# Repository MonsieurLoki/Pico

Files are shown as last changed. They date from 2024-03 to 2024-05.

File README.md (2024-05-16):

# Projet Pico Smart Fan
EPHEC, Technologies de l'Informatique, Electronique 2

Groupe J:
- Gaspard Derruine
- Maxime Malpica
- Hugo Noppe
- Dorian Kwizera

## Table of Contents

- [Introduction](#introduction)
- [Features](#features)
- [GitHub](#GitHub)

## Introduction

This is a group project from Ephec students in TI2, Electronics2

## Features

Project objectives :
- implement several functionalities on a Raspberry Pi Pico W
- monitor a temperature sensor and display it on a 2 digit 7-segment
    - use 2 SN74LS47N to drive the 7-segment digits
- when temperature is above MAX, activate fan until it's down below MAX-1
    - a simple 5v fan (DC motor) is used
    - a relay is used to ensure enough power can be given to the fan
    - (an extra power source is added to the Pico 5V source from the USB cable (or battery))
- a web server on the Pico allows to
    - consult that state of the system (temperature, etc)
    - manually control the fan (ON, OFF)
    - the MAX value can be updated with the web interface
- optional
    - implement an LCD 1602 display to show additional information
    - buzzer when temperature above MAX
    - vary the fan speed depending on the temperature (with PWM)
    - leds to indicate status
    - potentiometer (ADC) to adjust reference temperature
    - etc

## GitHub

https://github.com/MonsieurLoki/Pico

Le repository contient:
- les schémas et circuits du PCB
- le code
- le rapport d'avancement et le rapport final

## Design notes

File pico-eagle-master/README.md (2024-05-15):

# pico-eagle

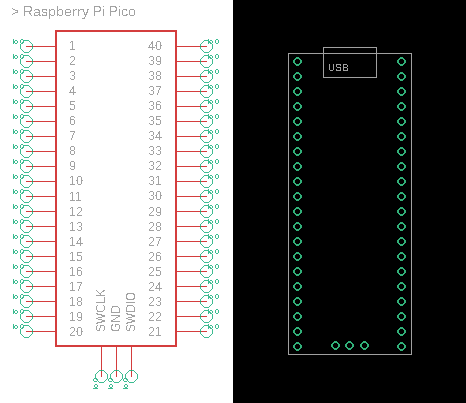
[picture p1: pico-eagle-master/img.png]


**A basic Eagle library for the Raspberry Pi Pico microcontroller board**

* Only a through-hole version is available

Created based on the [Raspberry Pi Pico datasheet](https://datasheets.raspberrypi.org/pico/pico-datasheet.pdf).

~~This has not been tested on an actual PCB - the most testing that has been done is a printed template to check everything looks like it lines up.~~ This has been tested on a PCB from JLCPCB, and it's perfect!

------



<p xmlns:cc="http://creativecommons.org/ns#"  xmlns:dct="http://purl.org/dc/terms/"><a property="dct:title"  rel="cc:attributionURL"  href="https://github.com/codemicro/pico-eagle">pico-eagle</a>  by <a rel="cc:attributionURL dct:creator"  property="cc:attributionName"  href="https://github.com/codemicro">Thomas Pain (codemicro)</a> is marked  with <a  href="http://creativecommons.org/publicdomain/zero/1.0?ref=chooser-v1"  target="_blank" rel="license noopener noreferrer"  style="display:inline-block;">CC0 1.0</p></a>

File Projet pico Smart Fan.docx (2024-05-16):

Mai 2024

Projet Pico Smart Fan

EPHEC, Technologies de l'Informatique, Electronique 2

Groupe J:

Gaspard Derruine

Maxime Malpica

Hugo Noppe

Dorian Kwizera

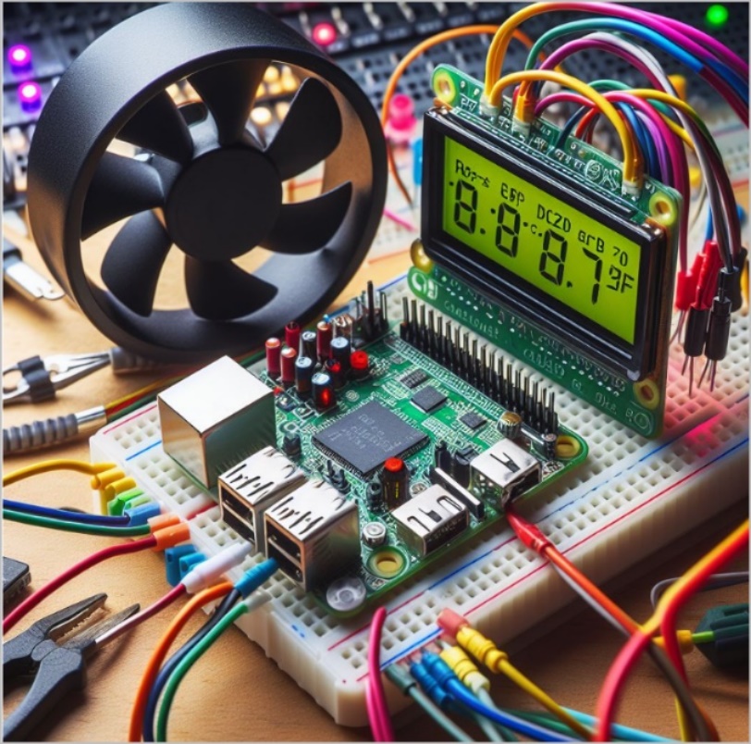
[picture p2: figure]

©DALL-E

# Objectifs du projet

- mettre en oeuvre les connaissances théoriques acquises durant les cours, le cours d'électronique principalement
- acquérir des compétences en matière de gestion de projet
- apprendre à travailler en groupe
- travailler dans le but d'atteindre un résultat concret

# Description du projet

Le groupe a proposé de développer un prototype de ventilateur intelligent, construit autour d'un microcontrôlleur.

Les caractéristiques du projet :

- lire un capteur de température et l'afficher sur un afficheur 7 segments à 2 chiffres.
- utiliser 2 SN74LS47N pour piloter les chiffres du 7 segments
- lorsque la température dépasse une température de référence donnée, activer le ventilateur jusqu'à ce qu'elle revienne à celle-ci
- piloter un ventilateur simple 5V (moteur CC)
- faire varier la vitesse du ventilateur en fonction de la température (avec PWM)
- mettre à jour la valeur de la température de référence avec une interface web
- implémenter un affichage LCD 1602 pour afficher des informations supplémentaires
- alerte sonore lorsque la température dépasse MAX
- LEDs pour indiquer l'état de la température

# Planning

Voici les étapes principales du projet :

- Janvier 2024 : présentation et démarrage du projet
- 21 Février : présentation idée de projet
- 18 Mars : rapport d'avancement
- Mars-Avril-Mai : travail de groupe
- 17 Mai : présentation du produit final

Les tâches détaillées sont reprises en Annexe 1.

# Simulation

Pour démarrer le projet, nous avons effectué quelques simulations de circuits sur Wokwi, mais nous sommes rapidement arrivés aux limites de ce qu'on peut faire d'utile pour un projet comme le nôtre, où la partir code est relativement importante.

# Le PCB

Le PCB a été développé sur l'outil Eagle, qui a demandé pas mal d'apprentissage. Le passage du schema logique au circuit a amené pas mal de surprises lorsque nous avons dû intégrer les contraintes physiques.

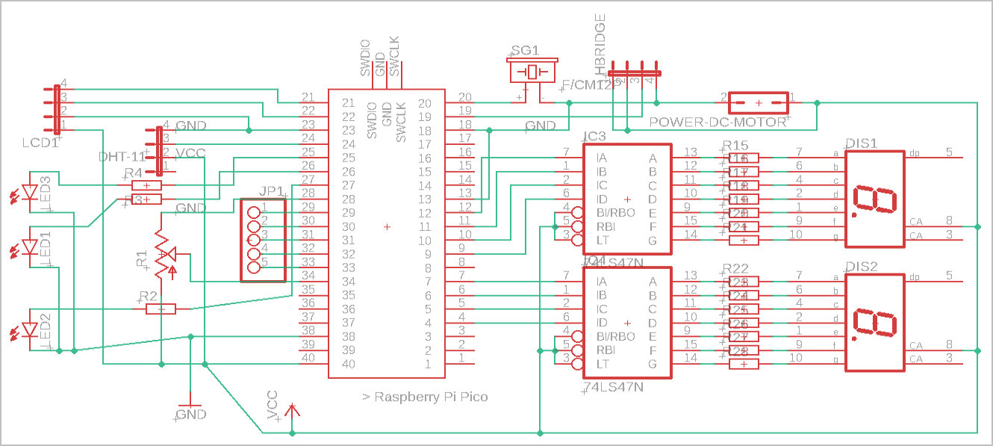
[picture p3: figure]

Ici aussi, les ressources offertes par Internet (tutos, YouTube, OpenAI etc) ont été fortement consultées.

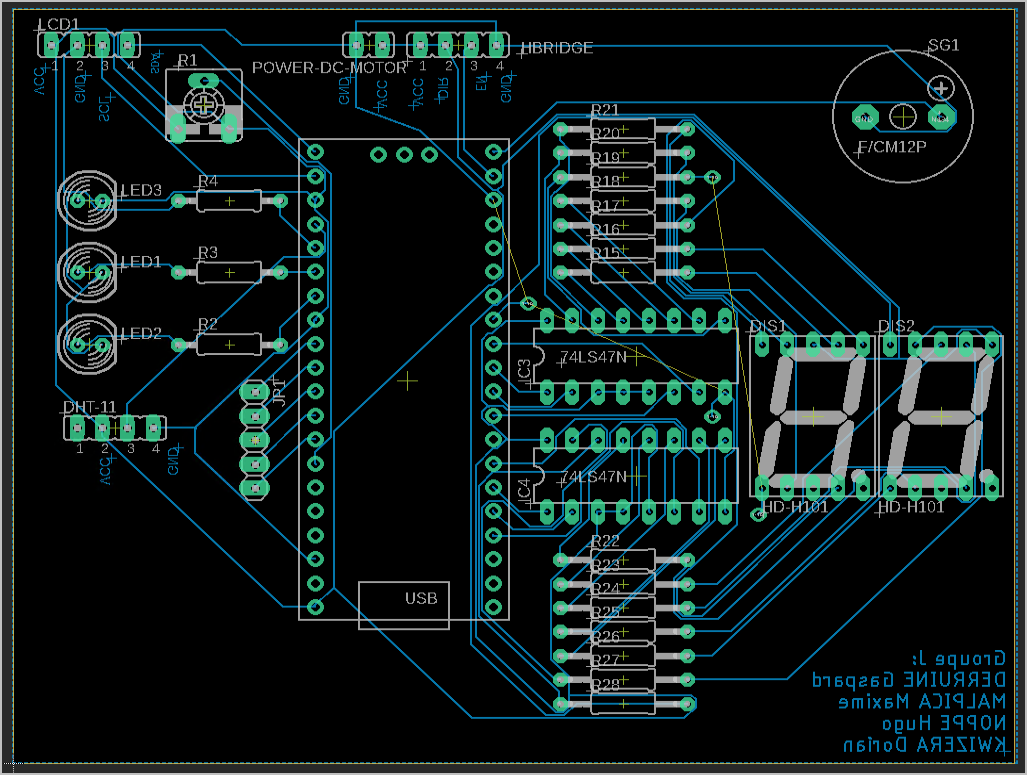
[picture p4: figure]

# Les composants

Les composants utilisés pour ce projet :

- Raspberry Pico W
- 2 74LS47 et 2 7segments + résistances de protection 220 ohms
- dht11
- LCD1602
- buzzer piezzo
- 3 leds
- potentiomètre 2K (ADC)
- ventilateur DC 5V
- PModHB5 (contrôleur moteur DC)

# Le code

Le code micropython a été réalisé de façon modulaire. Chaque composant (LEDs, 7segment + 74LS47, LCD, buzzer, moteur DC + PWM, potentiomètre ADC, etc) a son propre module python, ce qui permet de tester chaque composant individuellement, et de l'intégrer de façon très propre et très efficace dans le module principal du projet.

Le code est structuré de cette façon :

- main.py (main + wifi + webserver)
  - params.py (paramètres wifi)
  - 74LS47_7segments.py (affichage 7segments)
  - lcd.py (LDC1602)
  - dht11.py (capteur de temperature)
  - leds.py (leds)
  - buzzer.py (alarme sonore)

La partie la plus délicate a été la gestion évènementielle et les appels à des procédures asynchrones (que nous ne maîtrisons pas encore tout à fait).

# Github

Notre repository sur github : https://github.com/MonsieurLoki/Pico

Ce repository contient :

- les schémas pour le PCB
- le code micropython
- la documentation

# Le résultat final

Malgré les difficultés techniques et organisationnelles, nous sommes plutôt satisfaits du résultat final.

Notre projet fonctionne réellement et répond aux spécifications initiales. Nous avons appris énormément et avons plein d'idées sur la façon dont ce projet pourrait être continué, et comment un nouveau projet pourrait bénéficier de toute l'expérience acquise durant les semaines précédentes.

Le prototype final: L'interface web :

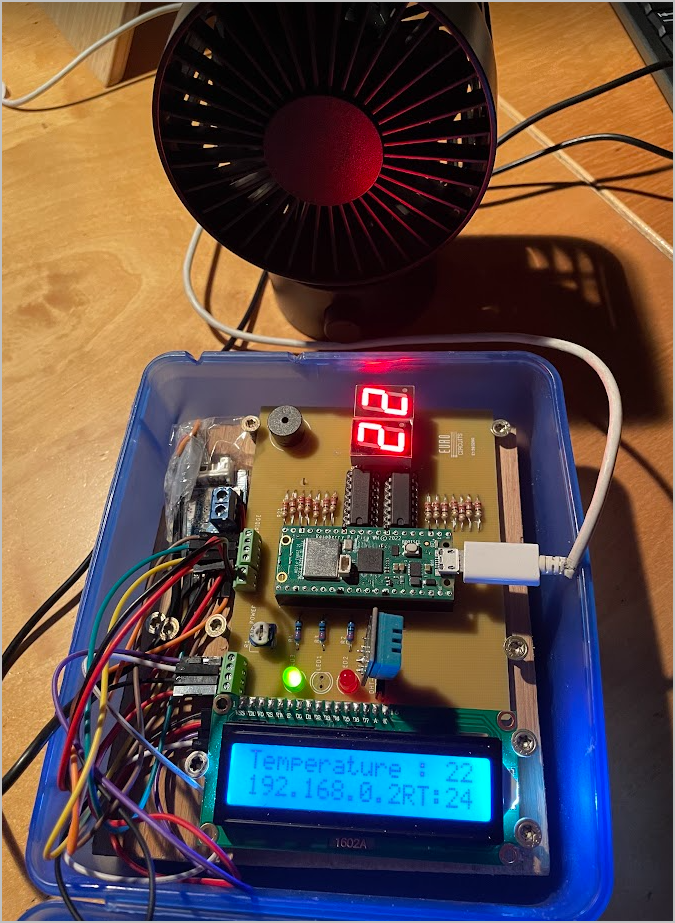
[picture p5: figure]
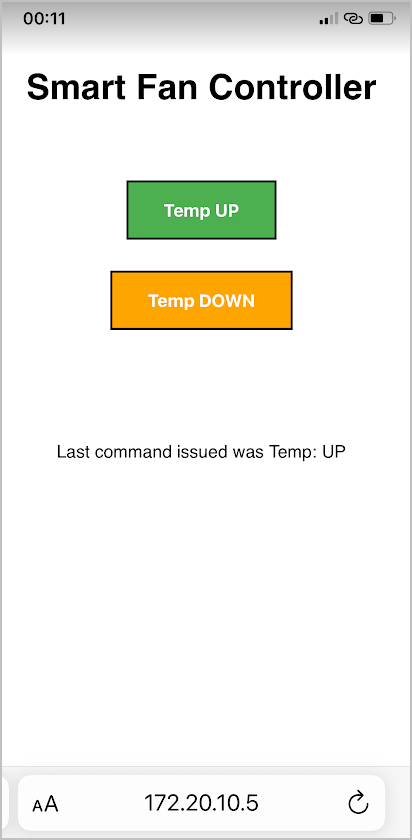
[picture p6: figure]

# Les difficultés rencontrées

## Le PCB

Le design et la réalisation du PCB a été une expérience complètement nouvelle pour tous les membres du groupe. La mise en pratique des techniques vues au cours a demandé pas mal d'efforts et a été une expérience relativement stressante, entre autres à cause du fait qu'il est difficile de simuler le bon fonctionnement du PCB avec les outils à notre disposition, et le fait que dès que le schéma du PCB part vers le fabricant, il est très compliqué de corriger une erreur de design.

## Le matériel

Les composants électroniques n'étant pas en nombre suffisant pour que tout le monde ait un exemplaire de chaque composant (et en particulier du PCB ), il a fallu se répartir les tâches autrement (contributions au design du PCB, à la documentation, au code, à l'implémentation des composants individuellement sur breadboard, etc). L'un de nous s'est consacré à l'intégration des composants sur le PCB et l'intégration du code.

## Micropython

Python est un langage nouveau pour la plupart des membres du groupe et le niveau de chacun est différent. Grâce à notre connaissance des langages appris dans les cours précédents (C, Javascript), et avec l'aide de l'IA, il a cependant été possible de réaliser la plupart des objectifs du projet, et surtout d'apprendre énormément.

## GitHub

Nous avons commencé à utiliser GitHub l'année dernière pour des projets individuels. Travailler en groupe avec GitHub, et surtout pour un projet en micropython sur un microcontroller, et moins évident, d'autant plus si tout le monde n'a pas tout le matériel à disposition.

## Le travail de groupe

Contribuer à un projet de développement de software en groupe, comme le projet Formule 1 du premier quadri, est une chose. Collaborer efficacement sur un projet matériel est plus compliqué, dû aux évidentes contraintes physiques.

# Extension possible du projet

Avec quelques jours de plus, les fonctionnalités suivantes seraient facilement implémentables sur notre prototype :

- consulter l'état du système (température, etc.) via l'appli web
- contrôler manuellement le ventilateur (MARCHE, ARRÊT) via l'appli web
- potentiomètre (ADC) pour ajuster la température de référence (celui-ci est déjà prévu dans le design initial et soudé sur le PCB)

# Conclusions

## Hugo

Personnellement j'ai trouvé ce projet très intéressant car il nous a introduit à la création de PCB, et la familiarisation aux microcomputer, c’est une expérience que je n’avais jamais eu l’occasion de faire. Cela m’ouvre des portes à la réalisation de plus grands projets personnels. Grâce à l’aide des profs nous avons su mener à bien ce projet.

## Dorian

J’ai finalement beaucoup aimé ce projet. La partie du codage me faisait un peu peur mais finalement, en allant d’étape en étape, cela c’est très bien passé et le résultat est encore mieux que l’attente initiale. Un des points négatif est le faite qu’une seul personne du groupe pouvait posséder du matériel à la fois, c’ était très compliqué à gérer. Il suffisait d’une absence pour devoir reporter tout une séance de labo par exemple. Mais l’expérience reste bien plus positif que négatif. Et surtout, Il m’a fait réaliser que le Raspberry Pi Pico pouvait nous permettre de contrôler de nombreuse chose de la vie de tous les jours sur notre téléphone (alarmes, garage, store pour fenêtre, chauffage,..) grâce à une page web définie et un serveur web créé pour la servir.

## Maxime

En conclusion, ce projet en électronique a été très enrichissant. La création d'un PCB, avec l'ajout de microcontrôleurs et de capteurs, nous a permis d'avoir un bon aperçu des projets en électronique. Cependant, j'étais stressé par le fait que nous n'avions jamais utilisé de PCB auparavant. Un problème de branchement ou de soudure peut rapidement poser des difficultés, mais heureusement, cela s'est bien passé. Le projet nous a également laissé un large choix pour notre créativité. Merci aux professeurs pour leur encadrement et leur aide à surmonter certains problèmes que nous avons rencontrés.

## Gaspard

Le défi du projet était relativement impressionnant au départ, vu nos connaissances théoriques et pratiques d'il y a quelques mois. Mais le fait d'avoir été poussé à atteindre des objectifs relativement ambitieux m'ont permis de me dépasser et de réaliser qu'en passant le temps nécessaire, et en cherchant suffisamment, principalement sur Internet, il est possible d'approfondir tout seul ou en groupe les concepts abordés au cours et de concrétiser ceux-ci dans un vrai projet. La satisfaction de voir ce montage électronique s'animer progressivement et finalement faire ce qu'on avait prévu qu'il fasse est très grande et m'encourage vraiment à continuer à explorer ce monde à la frontière entre électronique pure et développement de software. La combinaison des deux compétences ouvre des possibilités dont je n'avais pas la moindre idée jusqu'ici.

## Conclusion du groupe

Chacun s'accorde à dire que ce projet n'a pas été simple, qu'il a fallu investir pas mal de temps et d'effort, mais qu'il nous a permis d'apprendre énormément, dans des domaines qui étaient inconnus pour nous jusque-là. Le fait d'avoir un objectif ambitieux, mais aussi la guidance des profs qui nous ont convaincu que c'était possible d'y arriver, nous a finalement permis de dépasser les différentes difficultés techniques et organisationnelles. Le fait de travailler en groupe, au départ une contrainte, a aussi été l'occasion de s'enrichir mutuellement, certains étant plus forts dans certains domaines, et profitant des connaissances des autres dans d'autres.

En conclusion, ce projet restera un très bon souvenir et une excellente façon d'apprendre beaucoup pour réaliser un projet très concret.

# Références bibliographiques et autres

Ce projet a principalement été réalisé sur base des matières vues au cours, des labos et autres travaux pratiques préparatoires. Il n'y a donc pas vraiment de bibliographie à documenter.

Beaucoup de tutos ont été consultés, soit en version statique (wikis), soit en version vidéo (YouTube).

## Raspberry Pico

- Documentation Raspberry Pico : https://www.raspberrypi.com/documentation/microcontrollers/raspberry-pi-pico.html
- Instllation micropython sur Pico: https://www.youtube.com/watch?v=GiT3MzRzG48&ab_channel=CoreElectronics

## Pico micropython :

- Cette ressource en particulier nous a beaucoup aidé car elle nous a permis de comprendre et de régler un problème délicat, à savoir la gestion d'évènements asynchrones sur un microcontroller en micropython :

https://www.youtube.com/watch?v=AK8UYh7pMGM&t=1s&ab_channel=CoreElectronics

- Buzzer : https://www.youtube.com/watch?v=S4zPLBTC7_w
- Web Server : How To Setup a HTTP Web Server With Raspberry Pi Pico W (using WiFi) (https://www.youtube.com/watch?v=AK8UYh7pMGM&ab_channel=CoreElectronics)
- tuto H Bridge Motor Control Basics Explained (https://www.youtube.com/watch?v=YYMsS50x1UY&ab_channel=TheEngineeringMindset)
- tuto controlling motor with Hbridge (moteur : ig220019X00015r, controlleur :
- ow to sound a buzzer : https://www.freva.com/how-to-connect-a-buzzer-to-a-raspberry-pi-pico/
- Hbride DC motor controller : https://digilent.com/reference/pmod/pmodhb5/start
- tuto controlling a DC motor : https://how2electronics-com.translate.goog/dc-motor-fan-speed-controller-with-raspberry-pi-pico/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
- PWM on the Raspberry Pi Pico with MicroPython (https://www.youtube.com/watch?v=hqudYm-a_aU)
- i2c : https://electrocredible.com/raspberry-pi-pico-i2c-tutorial-examples/
- LCD1602 : https://electrocredible.com/raspberry-pi-pico-lcd-16x2-i2c-pcf8574-micropython/

# Annexe : liste détaillée des tâches

## Tasks

Done

- describe project and features
- test components individually
  - dht-11 (temperature sensor)
  - pmod5hb (HBridge driver for a DC motor)
    - fan working
    - speed can be adjusted
  - buzzer

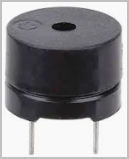
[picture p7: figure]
Alt text

- create github repository
- create first version PCB
- tools -> checks ERC (Electronic Rules Check) and DRC (Design Rules Check)
- add a ground plane

Todo

- make sure all group members have access to the github repo
- check everything (project, features, components, PBC, etc)
- in particular, check PCB
  - schematic : check that each component individually is connected properly (VCC, GND, GPIO)
  - board : check that all connections are done properly (top and bottom layers, no intersections, no hanging wire, etc)
  - optimize signals ( )
  - annotate pinheads on the board
  - check with https://eurocircuits.com
- test components individually
  - 7-segments led + 74LS47
  - LCD1602 display
  - onboard temperature sensor
  - ADC (with variable resistor - potentiometer)
- develop micropython functions to control each component individually, with the GPIOs as planned on the PCB
  - def getValuePot(): (return value between -5 and 5)
  - def initWifi()
  - def initWebServer()
  - def getTemperature()
  - def adjustFan(speed)
  - def displayLCDmsg(msg)
  - def display2digits(value)

## PCB

To be put on the PCB :

- Pico W
- 2x 7-segments DIGIT
  - 7 connections to SN74LS47
  - GND
- SN74LS47N nr 1 (unités)
  - 7 connections to 7-segment
  - GPIO 2 (D), 3 (C), 4 (B), 5 (A) : 4 bits -> 1 digit
  - BI/RBO, RBI, LT connected to VCC
- SN74LS47N nr 2 (dizaines)
  - 7 connections to 7-segment
  - GPIO 6 (D), 7 (C), 8 (B), 9 (A) : 4 bits -> 1 digit
  - BI/RBO, RBI, LT connected to VCC
- fan hbridge
  - GPIO 14 (ENABLE)
  - GND
  - VCC
  - DIRection : VCC (only one direction for the fan)
- buzzer
  - GPIO 15
  - GND
- variable resistor
  - VCC
  - GND
  - ADC 2 (GPIO 28)
- LCD 1602
  - VCC
  - GND
  - SDA (GPIO 16)
  - SCL (GPIO 17)
- DHT-11 sensor
  - GPIO 18 (signal)
  - VCC (5V)
  - GND
- led red
  - GPIO 19
- led red
  - GPIO 20
- led red
  - GPIO 21
- reserve PINs (just in case)
  - 1 : GPIO 22
  - 2 : RUN
  - 3 : GPIO 26
  - 4 : GPIO 27
  - 5 : GPIO 28

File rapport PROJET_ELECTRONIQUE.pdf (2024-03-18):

# Projet - ELECTRONIQUE DIGITALE - T2072

### NOPPE Hugo DERRUINE Gaspard MALPICA ARANA Maxime KWIZERA Dorian

### 18 mars 2024

## Table des matières

1 Introduction | 2
2 Répartition du travail | 2
3 Avancement général | 2
4 Schéma électronique | 3

## 1 Introduction

L’objectif principal de ce projet est de concevoir un proof of concept illustrant les bénéfices d’une maison intelligente. Pour cela, nous disposons d’une variété de capteurs et d’actionneurs, allant des simples boutons poussoirs aux capteurs de température et de mouvement.
Après avoir examiné les différentes possibilités, nous avons décidé de concentrer nos efforts sur la création d’un système autonome de régulation de la température. Notre choix s’est porté sur cette fonctionnalité en raison de sa pertinence dans le contexte de la domotique et de sa faisabilité dans le cadre du projet.
Concrètement, notre système permettra à l’utilisateur de définir une température seuil via une interface web. Le système surveillera ensuite en permanence la température ambiante à l’aide d’un capteur dédié. Si la température dépasse le seuil défini, un ventilateur sera activé pour réguler l’atmosphère. Les informations sur la température seront également affichées sur des afficheurs 7 segments, offrant ainsi une surveillance en temps réel de l’environnement.
Ce rapport présentera en détail notre démarche de conception et d’implémentation, ainsi que les résultats obtenus lors de la réalisation de ce projet.

## 2 Répartition du travail

Nous nous sommes chacun répartis plusieurs tâches. Gaspard à testé le materiel chez lui avec plusieurs petits programmes qu’il a confectionné afin de s’assurer que tout fonctionnait. Ensuite nous nous sommes retrouvés plusieurs fois à l’openlab tous ensembles afin de faire fonctionner tous les composants ensembles. Maxime et Dorian ont travaillés sur les branchements pendant qu’Hugo écrivait le code pour faire fonctionner ces derniers. En parallèle Gaspard à travaillé sur Eagle et nous avons tous vérifié le travail. Finalement Hugo à fini par rédiger ce rapport pour présenter l’avancement du projet. Nous avons également pu profiter de github pour centraliser tout notre travail et se partager les différents fichiers.

## 3 Avancement général

Pour le projet nous avons fini la partie Eagle. Les branchements et la beadboard sont totalement finis. Le code est encore à améliorer. Nous devons juste relier le moteur au système et créer l’interface web pour le programme. Nous avons cependant déjà fait fonctionner le moteur graçe à un code. Celui ci ne doit plus qu’être intégré au reste du code.
Plus de détail se trouve dans le github : https://github.com/MonsieurLoki/Pico

## 4 Schéma électronique

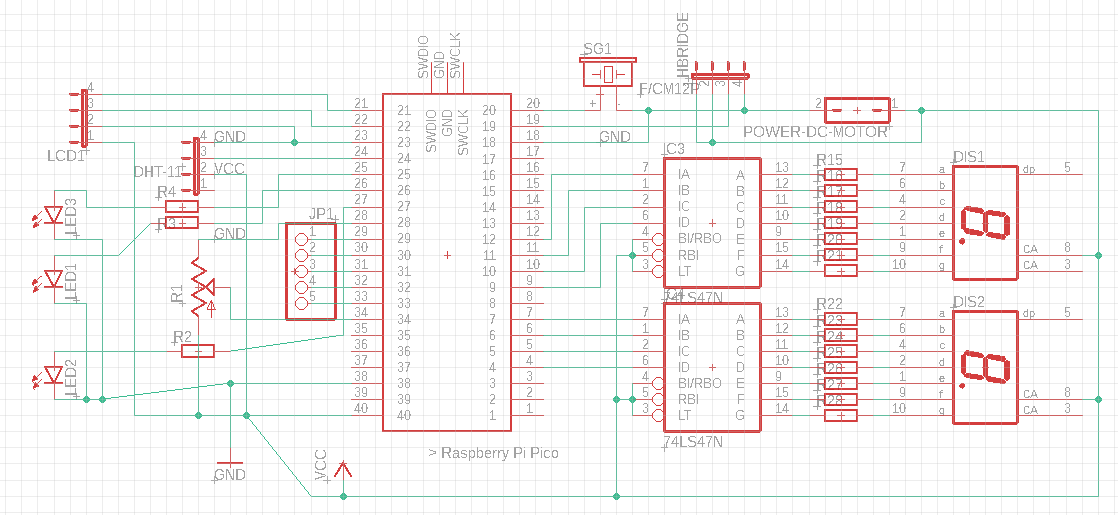
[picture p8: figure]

Figure 1 – Schematic

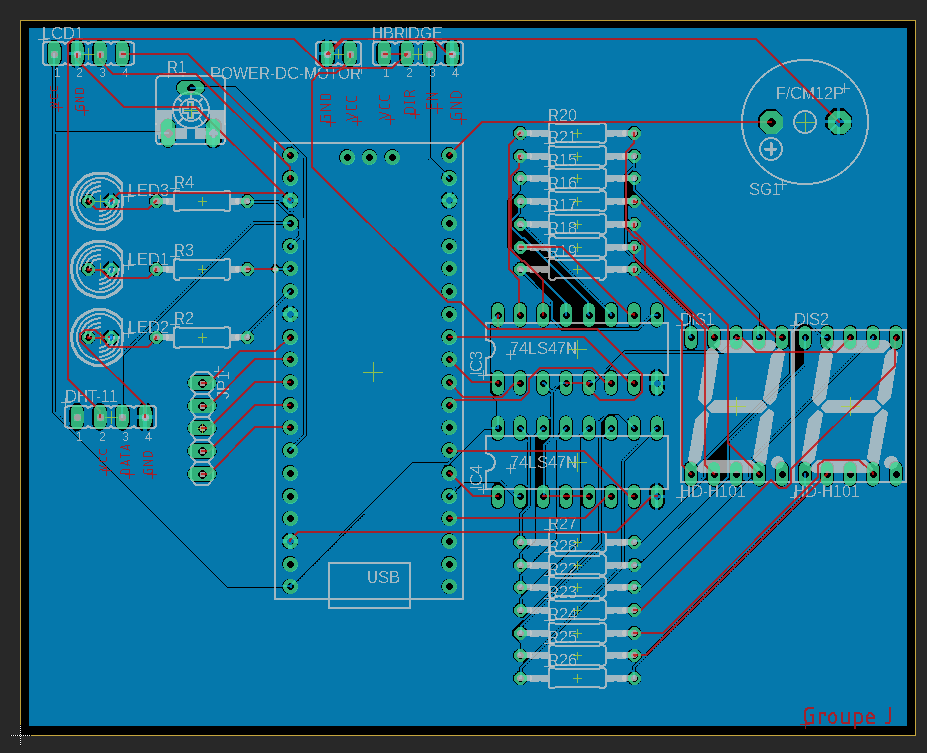
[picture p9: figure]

Figure 2 – Board

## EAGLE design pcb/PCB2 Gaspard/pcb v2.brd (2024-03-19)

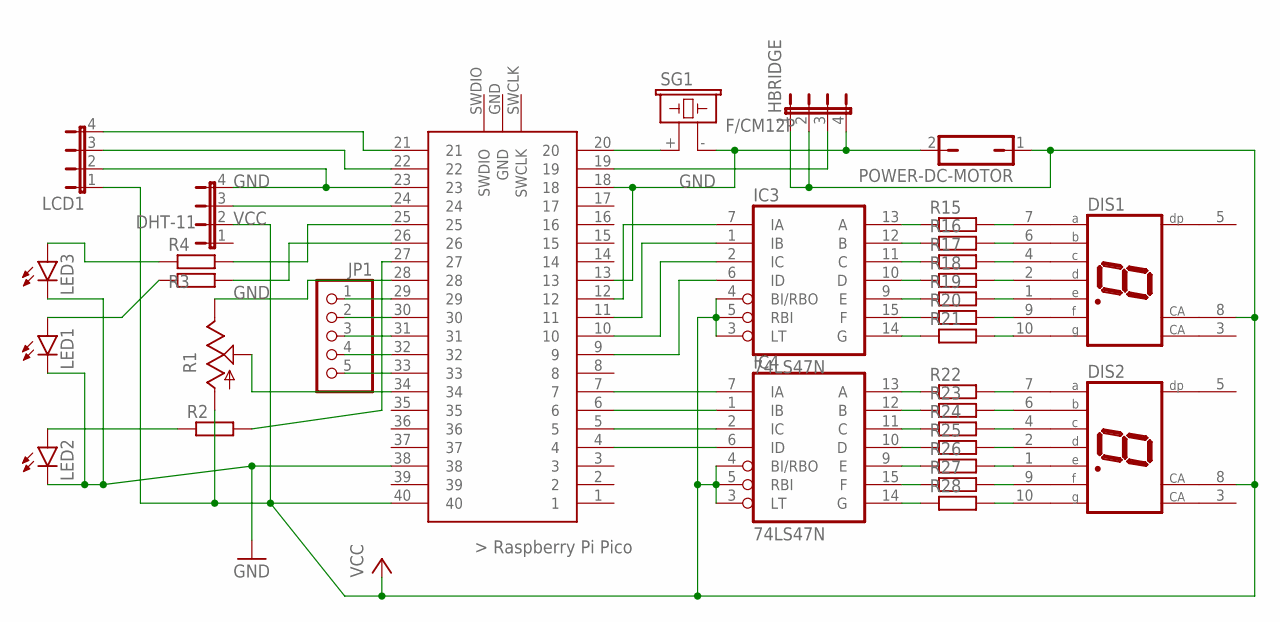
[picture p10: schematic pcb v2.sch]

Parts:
DHT-11: JP4E; JP4
DIS1, DIS2: HD-H101; HDSP-M
HBRIDGE: JP4E; JP4
IC3, IC4: 74LS47N; DIL16
JP1: PINHD-1X5; 1X05
LCD1: JP4E; JP4
LED1, LED2, LED3: LED5MM
POWER-DC-MOTOR: JP1Q; JP1
R1: TRIM_US-CA6V; CA6V
R2, R3, R4: R-EU_0207/10; 0207/10
R15, R16, R17, R18, R19, R20, R21, R22, R23, R24, R25, R26, R27, R28: R-EU_0207/12; 0207/12
SG1: F/CM12P
U$1: RASPBERRY-PI-PICO_TH; FT_RASPBERRY-PI-PICO_TH

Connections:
GND: DHT-11.4, HBRIDGE.4, IC3.8 (GND), IC4.8 (GND), LCD1.2, LED1.K (C), LED2.K (C), LED3.K (C), POWER-DC-MOTOR.2, R1.E, SG1.- (2), U$1.13, U$1.18, U$1.23, U$1.28, U$1.38
unnamed: IC4.7 (IA), U$1.7
unnamed: IC4.1 (IB), U$1.6
unnamed: IC4.2 (IC), U$1.5
unnamed: IC4.6 (ID), U$1.4
unnamed: R1.S, U$1.34
unnamed: IC3.14 (G), R21.1
unnamed: DIS2.7 (A), R22.2
unnamed: DIS2.6 (B), R23.2
unnamed: DIS2.4 (C), R24.2
unnamed: DIS2.2 (D), R25.2
unnamed: DIS2.1 (E), R26.2
unnamed: DIS1.10 (G), R21.2
unnamed: IC3.6 (ID), U$1.9
unnamed: IC3.2 (IC), U$1.10
unnamed: IC3.1 (IB), U$1.11
unnamed: IC3.7 (IA), U$1.12
unnamed: DIS2.9 (F), R27.2
unnamed: DIS2.10 (G), R28.2
unnamed: IC4.13 (A), R22.1
unnamed: IC4.12 (B), R23.1
unnamed: IC4.11 (C), R24.1
unnamed: DIS1.7 (A), R15.2
unnamed: DIS1.6 (B), R16.2
unnamed: DIS1.4 (C), R17.2
unnamed: DIS1.2 (D), R18.2
unnamed: DIS1.1 (E), R19.2
unnamed: JP1.1, U$1.29
unnamed: JP1.2, U$1.30
unnamed: IC4.10 (D), R25.1
unnamed: IC4.9 (E), R26.1
unnamed: IC4.15 (F), R27.1
unnamed: IC4.14 (G), R28.1
unnamed: SG1.+ (1), U$1.20
unnamed: JP1.3, U$1.31
unnamed: DIS1.9 (F), R20.2
unnamed: IC3.13 (A), R15.1
unnamed: IC3.12 (B), R16.1
unnamed: IC3.11 (C), R17.1
unnamed: IC3.10 (D), R18.1
unnamed: IC3.9 (E), R19.1
unnamed: IC3.15 (F), R20.1
unnamed: HBRIDGE.3, U$1.19
unnamed: JP1.4, U$1.32
unnamed: DHT-11.3, U$1.24
unnamed: LCD1.4, U$1.21
unnamed: LCD1.3, U$1.22
unnamed: JP1.5, U$1.33
unnamed: R2.2, U$1.27
unnamed: R4.2, U$1.25
unnamed: R3.2, U$1.26
unnamed: LED2.A, R2.1
unnamed: LED1.A, R3.1
unnamed: LED3.A, R4.1
VCC: DHT-11.2, DIS1.8 (CA), DIS2.8 (CA), HBRIDGE.1, HBRIDGE.2, IC3.3 (LT), IC3.4 (BI/RBO), IC3.5 (RBI), IC3.16 (VCC), IC4.3 (LT), IC4.4 (BI/RBO), IC4.5 (RBI), IC4.16 (VCC), LCD1.1, POWER-DC-MOTOR.1, R1.A, U$1.40

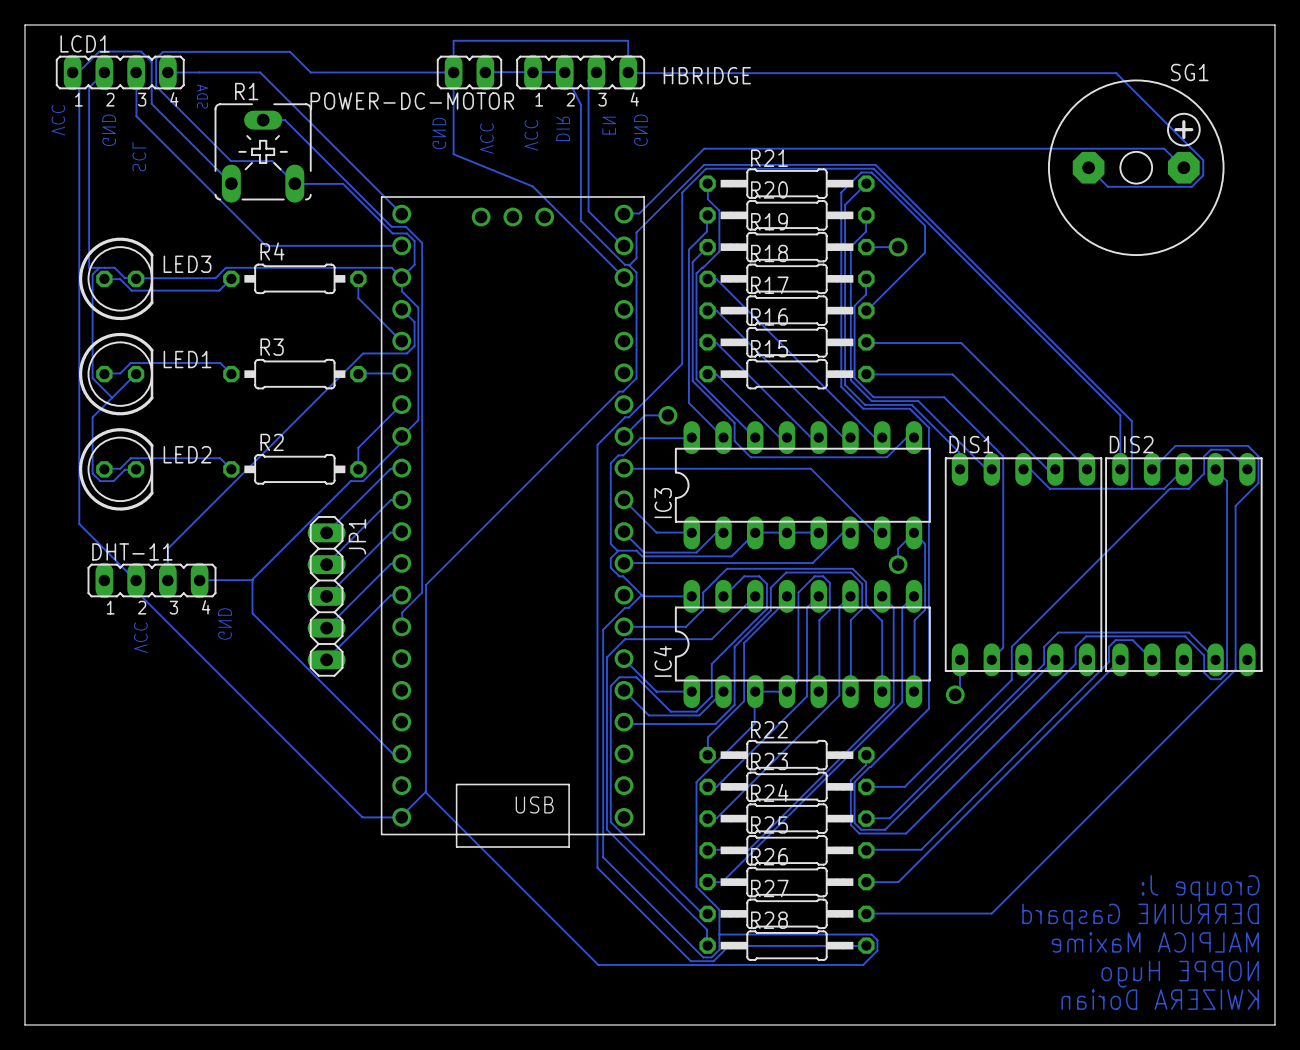
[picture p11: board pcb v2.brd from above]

Board: 2 copper layers, 100.0 x 80.0 mm, 32 parts (0 on the bottom side), 55 nets.

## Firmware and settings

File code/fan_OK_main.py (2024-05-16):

"""
Smart Fan project

EPHEC, Technologies de l'Informatique, Electronique 2
Mai 2024

Groupe J:
Gaspard Derruine
Maxime Malpica
Hugo Noppe
Dorian Kwizera

"""
import time
import network
import uasyncio as asyncio
from machine import Pin, PWM

import fan_OK_params as params
import fan_OK_74LS47_7segments as seg7
import fan_OK_lcd_1602 as lcd



import fan_OK_dht11 as dht11
import fan_OK_leds as fan_leds
import fan_OK_buzzer_PWM as buzzer
import fan_OK_hbridge as hbridge


# enable_pin = Pin(14, Pin.OUT)	# ENABLE of the PmodHb5 (dc motor controller)
previous_temp = 0
ref_temp = 24

# # Hardware definitions
# led = Pin("LED", Pin.OUT, value=1)
# pin_up = Pin(14, Pin.OUT, value=0)		# green led
# pin_down = Pin(15, Pin.OUT, value=0)   	# orange led
# pin_stop = Pin(14, Pin.OUT, value=0)	# red led
# 
# Configure your WiFi SSID and password

check_interval_sec = 0.5
# check_interval_sec = 1

wlan = network.WLAN(network.STA_IF)


# The following HTML defines the webpage that is served
html = """<!DOCTYPE html><html>
<head><meta name="viewport" content="width=device-width, initial-scale=1">
    <link rel="icon" href="data:,">
<style>
html { font-family: Helvetica; display: inline-block; margin: 0px auto; text-align: center;}
.buttonGreen { background-color: #4CAF50; border: 2px solid #000000;; color: white; padding: 15px 32px; text-align: center; text-decoration: none; display: inline-block; font-size: 16px; margin: 4px 2px; cursor: pointer; }
.buttonRed { background-color: #d11d53; border: 2px solid #000000;; color: white; padding: 15px 32px; text-align: center; text-decoration: none; display: inline-block; font-size: 16px; margin: 4px 2px; cursor: pointer; }
.buttonOrange { background-color: orange; border: 2px solid #000000;; color: white; padding: 15px 32px; text-align: center; text-decoration: none; display: inline-block; font-size: 16px; margin: 4px 2px; cursor: pointer; }
text-decoration: none; font-size: 30px; margin: 2px; cursor: pointer;}
</style></head>
<body><center><h1>Smart Fan Controller</h1></center><br><br>
<form><center>
<center> <button class="buttonGreen" name="TEMP" value="UP" type="submit">Temp UP</button>
<br><br>
<center> <button class="buttonOrange" name="TEMP" value="DOWN" type="submit">Temp DOWN</button></center>
</center></form>
<br><br>
<br><br>
<p>Last command issued was %s<p></body></html>
"""


# def blink_led(frequency = 0.5, num_blinks = 3):
#     for _ in range(num_blinks):
#         led.on()
#         time.sleep(frequency)
#         led.off()
#         time.sleep(frequency)

def control_temp(cmd):
    global ref_temp
    
    if cmd == 'up':
        ref_temp += 1
    
    if cmd == 'down':
        ref_temp -= 1
        
        
async def connect_to_wifi():
    wlan.active(True)
    wlan.config(pm = 0xa11140)  # Diable powersave mode
    wlan.connect(params.ssid, params.password)

    # Wait for connect or fail
    max_wait = 15
    while max_wait > 0:
        if wlan.status() < 0 or wlan.status() >= 3:
            break
        max_wait -= 1
        print('waiting for connection...')
        time.sleep(1)

    # Handle connection error
    if wlan.status() != 3:
#         blink_led(0.1, 10)
        raise RuntimeError('WiFi connection failed')
    else:
#         blink_led(0.5, 2)
        print('connected')
        status = wlan.ifconfig()
        print('ip = ' + status[0])
        
        status = wlan.ifconfig()
        
        lcd.lcd.move_to(0,1)
        lcd.lcd.putstr(f'{status[0]}')
        buzzer.play(buzzer.wifi_notif)

#        time.sleep(1)


async def serve_client(reader, writer):
    print("Client connected")
    request_line = await reader.readline()
    print("Request:", request_line)
    # We are not interested in HTTP request headers, skip them
    while await reader.readline() != b"\r\n":
        pass
    
    # find() valid garage-door commands within the request
    request = str(request_line)
    cmd_up = request.find('TEMP=UP')
    cmd_down = request.find('TEMP=DOWN')
    cmd_stop = request.find('TEMP=STOP')
    print ('TEMP=UP => ' + str(cmd_up)) # show where the commands were found (-1 means not found)
    print ('TEMP=DOWN => ' + str(cmd_down))
    print ('TEMP=STOP => ' + str(cmd_stop))

    stateis = "" # Keeps track of the last command issued
    
    # Carry out a command if it is found (found at index: 8)
    if cmd_up == 8:
        stateis = "Temp: UP"
        print(stateis)
        control_temp('up')
        lcd.lcd.move_to(0,1)
        lcd.lcd.putstr("cmd: UP           ")

        
    elif cmd_down == 8:
        stateis = "Temp: DOWN"
        print(stateis)
        control_temp('down')
        lcd.lcd.move_to(0,1)
        lcd.lcd.putstr("cmd: DOWN         ")
    
    response = html % stateis
    writer.write('HTTP/1.0 200 OK\r\nContent-type: text/html\r\n\r\n')
    writer.write(response)

    await writer.drain()
    await writer.wait_closed()


async def main():
    lcd.setup_lcd()

    lcd.lcd.clear()
    lcd.lcd.move_to(0,0)
    lcd.lcd.putstr("Start async fan")
    print('Connecting to WiFi...')
    asyncio.create_task(connect_to_wifi())

    print('Setting up webserver...')
    asyncio.create_task(asyncio.start_server(serve_client, "0.0.0.0", 80))

    seg7.setup_74LS47()
#     seg7.check_74LS47()

    i = 1
    while True:
        print(i)
        await asyncio.sleep(check_interval_sec)
        i+=1
        dht11.read_and_display_data()
        print(i, "temperature:", dht11.temperature, "  humidity:", dht11.humidity)
        lcd.lcd.move_to(0,0)
        lcd.lcd.putstr(f'Temp:{dht11.temperature} (RT:{ref_temp}) ')
               
        
        if dht11.temperature >ref_temp:
            fan_leds.r_led.value(1)
            fan_leds.g_led.value(0)
#             enable_pin.value(1)
            if dht11.temperature == ref_temp+1:
                hbridge.set_fan_speed(60)
            elif dht11.temperature == ref_temp+2:
                hbridge.set_fan_speed(75)
            else:
                hbridge.set_fan_speed(100)
                
            print(f'previous_temp:{previous_temp},ref_temp:{ref_temp}')
            if previous_temp == ref_temp:
                buzzer.play(buzzer.alarm)
            
            
        if dht11.temperature <=ref_temp:
            fan_leds.r_led.value(0)
            fan_leds.g_led.value(1)
#             enable_pin.value(0)
            hbridge.set_fan_speed(0)
        
        seg7.displayDigit(0,dht11.temperature % 10)
        seg7.displayDigit(1,dht11.temperature // 10)
        
        previous_temp = dht11.temperature


try:
    asyncio.run(main())
finally:
    asyncio.new_event_loop()

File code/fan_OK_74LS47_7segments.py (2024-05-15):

#
# Basic 7-segment display test
#

from machine import Pin
import time


# 74LS47 nr 0 (digit for the units)
A0_PIN = 5
B0_PIN = 4
C0_PIN = 3
D0_PIN = 2

# 74LS47 nr 1 (digit for the tens)
A1_PIN = 9
B1_PIN = 8
C1_PIN = 7
D1_PIN = 6

def setup_74LS47():
    global A0, B0, C0, D0
    global A1, B1, C1, D1
    
    A0 = Pin(A0_PIN, Pin.OUT)
    B0 = Pin(B0_PIN, Pin.OUT)
    C0 = Pin(C0_PIN, Pin.OUT)
    D0 = Pin(D0_PIN, Pin.OUT)
    
    A1 = Pin(A1_PIN, Pin.OUT)
    B1 = Pin(B1_PIN, Pin.OUT)
    C1 = Pin(C1_PIN, Pin.OUT)
    D1 = Pin(D1_PIN, Pin.OUT)
       
def getBits(digit):
    d = digit
    bit1 = d % 2
    d = d // 2
    bit2 = d % 2
    d = d // 2
    bit3 = d % 2
    d = d // 2
    bit4 = d % 2

    return [bit1, bit2, bit3, bit4]

def displayDigit(nr_7segment,digit):
    global A0, B0, C0, D0 
    global A1, B1, C1, D1 

    bits = getBits(digit)

    if nr_7segment == 0:
        A0.off()
        B0.off()
        C0.off()
        D0.off()

        if bits[0] > 0: A0.on()
        if bits[1] > 0: B0.on()
        if bits[2] > 0: C0.on()
        if bits[3] > 0: D0.on()
    
    if nr_7segment == 1:
        A1.off()
        B1.off()
        C1.off()
        D1.off()

        if bits[0] > 0: A1.on()
        if bits[1] > 0: B1.on()
        if bits[2] > 0: C1.on()
        if bits[3] > 0: D1.on()
    
    #print(f'nr_7segment:{nr_7segment}, digit:{digit} -> {bits[3]}{bits[2]}{bits[1]}{bits[0]}')
    
def spinner():
    delay = 0.2
    for i in range(5):
        displayDigit(0,10)
        displayDigit(1,10)
        time.sleep(delay)
        displayDigit(0,12)
        displayDigit(1,12)
        time.sleep(delay)
        displayDigit(0,11)
        displayDigit(1,11)
        time.sleep(delay)

def blank_7segments():
    displayDigit(0,15)
    displayDigit(1,15)
    
def test_7segments_OK():
    for i in range(5):
        displayDigit(0,8)
        displayDigit(1,8)
        time.sleep(1)
        blank_7segments()
        time.sleep(0.1)

#    blink_7segments(8)

def blink_7segments(digit):    
    for i in range(5):
        displayDigit(0,digit)
        displayDigit(1,digit)
        time.sleep(0.1)
        blank_7segments()
        time.sleep(0.1)

def countdown_7segment():
    # countdown
    i = 0
    while i<1:
        for digit in range(9,-1,-1):
            print(digit)
            displayDigit(0,digit)
            displayDigit(1,digit)
            time.sleep(1)
        i += 1

def check_74LS47_10_to_15():
    # check digits from 10 to 15
    for digit in range(10,16):
        print(digit)
        displayDigit(0,digit)
        displayDigit(1,digit)
        time.sleep(1)

def check_74LS47():
    # this is the opportunity to make some adjustments...

    print("test 7segments (diodes) are OK")
    test_7segments_OK()
    
    print("countdown")
    countdown_7segment()
    blink_7segments(0)
              
    blank_7segments()
    time.sleep(1)

    print("check digits 10 to 15")
    check_74LS47_10_to_15()

    blank_7segments()
    time.sleep(1)
    
    spinner()
    blank_7segments()
        

#- main ------------------------------------------------------------
def main():
    #try:
    setup_74LS47()
    check_74LS47()

    # except KeyboardInterrupt:
    #     # Handle Ctrl+C gracefully
    #     print("KeyboardInterrupt")    
    #     print("machine reset")
    #     machine.reset()

if __name__ == "__main__":
    main()

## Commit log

2024-03-16 ajout shéma
    [pico.brd, pico.sch]
2024-03-17 update schémas
    [pico v2.brd, pico v2.sch]
2024-03-18 update after check drc erc
    [pico-v3-temp1.brd, pico-v3-temp1.sch, pico-v3.brd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]
2024-03-19 update isolate width
    [pico-v3.brd, pico-v3.sch]
2024-03-19 ajout de tout les fichiers dans archives et la version finale dans pcb2 gaspard
    [pcb v2.brd, pcb v2.sch, pcb.brd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]

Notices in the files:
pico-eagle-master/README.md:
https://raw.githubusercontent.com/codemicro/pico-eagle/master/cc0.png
